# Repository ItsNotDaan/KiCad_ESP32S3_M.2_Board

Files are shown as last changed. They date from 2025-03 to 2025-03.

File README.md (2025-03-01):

## ESP32-S3, M.2 based System on Module (SOM)

This is my first KiCad project, developed over the last 2 months alongside my EPS project and work. 

[KiCanvas Webpreview of latest version](https://kicanvas.org/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)

### Main Components

- **CPU:** ESP32-S3R8
- **Flash:** W25Q16JVUXIQ (16MBIT)
- **Crystals:** 40MHz and 32.768KHz (HSE/LSE)
- **Power/Flashing/Debugging:** USB-C
- **Buck Converter:** TLV62568DBV
- **Buttons:** Two buttons for RESET and BOOT
- **Antenna:** Antenna with PI filter
- **PCB:** 4-layer PCB (Top, GND, VCC, Bottom), internal planes are hidden

All these components are included on a M.2-B-Key footprint. 

### Inspiration

The idea originated from a desire to create a more complex and smaller PCB that incorporates an expensive CPU. This CPU should be versatile enough to be used on different projects. After watching a video from Phil's Lab, I learned that M.2 was a great alternative to the mostly used header pin setup. 

### Future Plans

The ESP32-S3 is not high-end or anything special, but I plan to quickly redesign this board using the newly announced ESP32-P4. It is a really interesting and high-speed CPU based on the RISC-V architecture and I'm excited to start creating some (DSP) code with it. 

I have ordered the components and the PCB to start experimenting with it.

https://www.linkedin.com/in/daan-heetkamp/

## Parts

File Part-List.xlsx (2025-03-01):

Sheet: Parts
Designator | Value | Comment | MFR.Part # | JLCPCB Part # | Package | Manufacturer | Needs to be changed/bought? | Link
ANT1 | KH-3216-H0209 | 1206 Antennas | KH-3216-H0209 | C2925417 | 1206 | Shenzhen Kinghelm Elec | No | https://wmsc.lcsc.com/wmsc/upload/file/pdf/v2/lcsc/2404011707_Espressif-Systems-ESP32-S3FN8_C2913196.pdf
C | 3.3e-12 | 50V 3.3pF C0G 0603 | 0603CG3R3C500NT | C1660 | 0603 | FH (Guangdong Fenghua Advanced Tech)
C | 1e-11 | 50V 10pF NP0 ±5% 0402 | C1005NP0100JGTS | C258501 | 0402 | Darfon Elec |  | https://www.lcsc.com/datasheet/lcsc_datasheet_1809211012_KDS-Daishinku-DST310S-32-768KHz_C93232.pdf
C | 2e-11 | 50V 20pF NP0 ±5% 0402 | CC0402JRNPO9BN200 | C107000 | 0402 | YAGEO | No
C | 1e-07 | 25V 100nF X5R ±10% 0402 | C1005X5R1E104KT000E | C361203 | 0402 | TDK |  | https://www.lcsc.com/datasheet/lcsc_datasheet_2205122030_Winbond-Elec-W25Q16JVUXIQ_C2843335.pdf
C | 1e-06 | 10V 1uF X5R ±20% 0402 | CC0402MRX5R6BB105 | C113791 | 0402 | YAGEO | No | https://www.lcsc.com/datasheet/lcsc_datasheet_2108132230_TECH-PUBLIC-USBLC6-2SC6_C2827654.pdf
C | 4.7e-06 | 6.3V 4.7uF X5R ±20% 0402 | GRM155R60J475ME47D | C82453 | 0402 | Murata Electronics |  | http://www.world-semi.com/DownLoadFile/139
C | 1e-05 | 10V 10uF X5R ±20% 0402 | 0402X106M100CT | C2992625 | 0402 | Walsin Tech Corp
D | RED | 0402 LED Indication - Discrete ROHS | XL-1005SURC | C25503345 | 0402 | XINGLIGHT | Yes
J | USB-C | 12P Female Type-C SMD USB Connectors | MC-311D | C136423 | SMD | SOFNG | Yes
L | 2.2e-6 | 3.4A 2.2uH ±20% 3.4A SMD,4x4x2mm Power Inductors ROHS | SMNR4020-2.2UH | C135262 | SMD,4x4x2mm | SXN(Shun Xiang Nuo Elec) | No | https://www.lcsc.com/datasheet/lcsc_datasheet_2009111836_SOFNG-MC-311D_C136423.pdf
L | 2.2e-9 | 500mA 2.2nH 100mΩ 0603 | SDCL1608C2N2STDF | C29682 | 0603 | Sunlord
LED | WS2812C-2020-V1 | Intelligent control LED integrated light source | WS2812C-2020-V1 | C2976072 | SMD,2x2mm | Worldsemi | No
R | 22 | 22Ω 0402 50V 100mW ±100ppm | ERJ2RKF22R0X | C413049 | 0402 | PANASONIC
R | 5100 | 5k1Ω 0402 50V ±100ppm | RC0402JR-075K1L | C105873 | 0402 | YAGEO | No
R | 10000 | 10kΩ 0402 50V 62,5mW ±100ppm | WR04X1002FTL | C163810 | 0402 | Walsin Tech Corp
R | 100000 | 100kΩ 0402 50V ±50ppm | RT0402CRE07100KL | C705662 | 0402 | YAGEO | No
R | 450000 | 450kΩ 0402 50V 62,5mW ±100ppm | FRC0402F4503TS | C5159688 | 0402 | FOJAN
S | EVQP2P02W | 20mA 4.7mm 100MΩ 1,000,000 Times 1N 15V 3.5mm 2.5mm Rectangle button | EVQP2P02W | C512395 | SMD,3.5x4.7mm | PANASONIC | No
U | ESP32-S3R8 | Microcontroller, Wi-Fi 802.11b/g/n, Bluetooth, 32bit | ESP32-S3R8 | C2913194 | QFN-56-EP(7x7) | Espressif Systems | No
U | TLV62568DBVR | 5.5V 1A SOT-23-5 DC-DC Converters RoHS | TLV62568DBVR | C163219 | SOT-23-5 | Texas Instruments | No
U | USBLC6-2SC6 | (TVS/ESD) 6A 12V 150W 6V Unidirectional 5V SOT-23-6 ESD and Surge Protection | USBLC6-2SC6 | C2827654 | SOT-23-6 | TECH PUBLIC | No
U | W25Q16JVUXIQ | USON-8-EP(2x3) NOR FLASH | W25Q16JVUXIQ | C2843335 | USON-8-EP(2x3) | Winbond Elec | No
Y | 32.768KHz | SMD3215-2P Crystals ROHS - 32.768KHz | DST310S 32.768KHz | C93232 | SMD3215-2P | KDS Daishinku | No
Y | 40MHz | 40MHz SMD crystal oscillator 10pF ±10ppm ±20ppm SMD2520-4P Crystals ROHS | X252040MMB4SI | C2885592 | SMD2520-4P | YXC Crystal Oscillators | No

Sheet: Sheet3
Done? | Comment | MFR.Part # | JLCPCB Part # | Package | Manufacturer
Yes
Yes
Yes
Yes
Yes
Yes
Yes
Yes
Yes
Yes
Yes
Yes
Yes
Yes
Yes
No
Yes
Yes
Yes
Yes
Yes
Yes
Yes

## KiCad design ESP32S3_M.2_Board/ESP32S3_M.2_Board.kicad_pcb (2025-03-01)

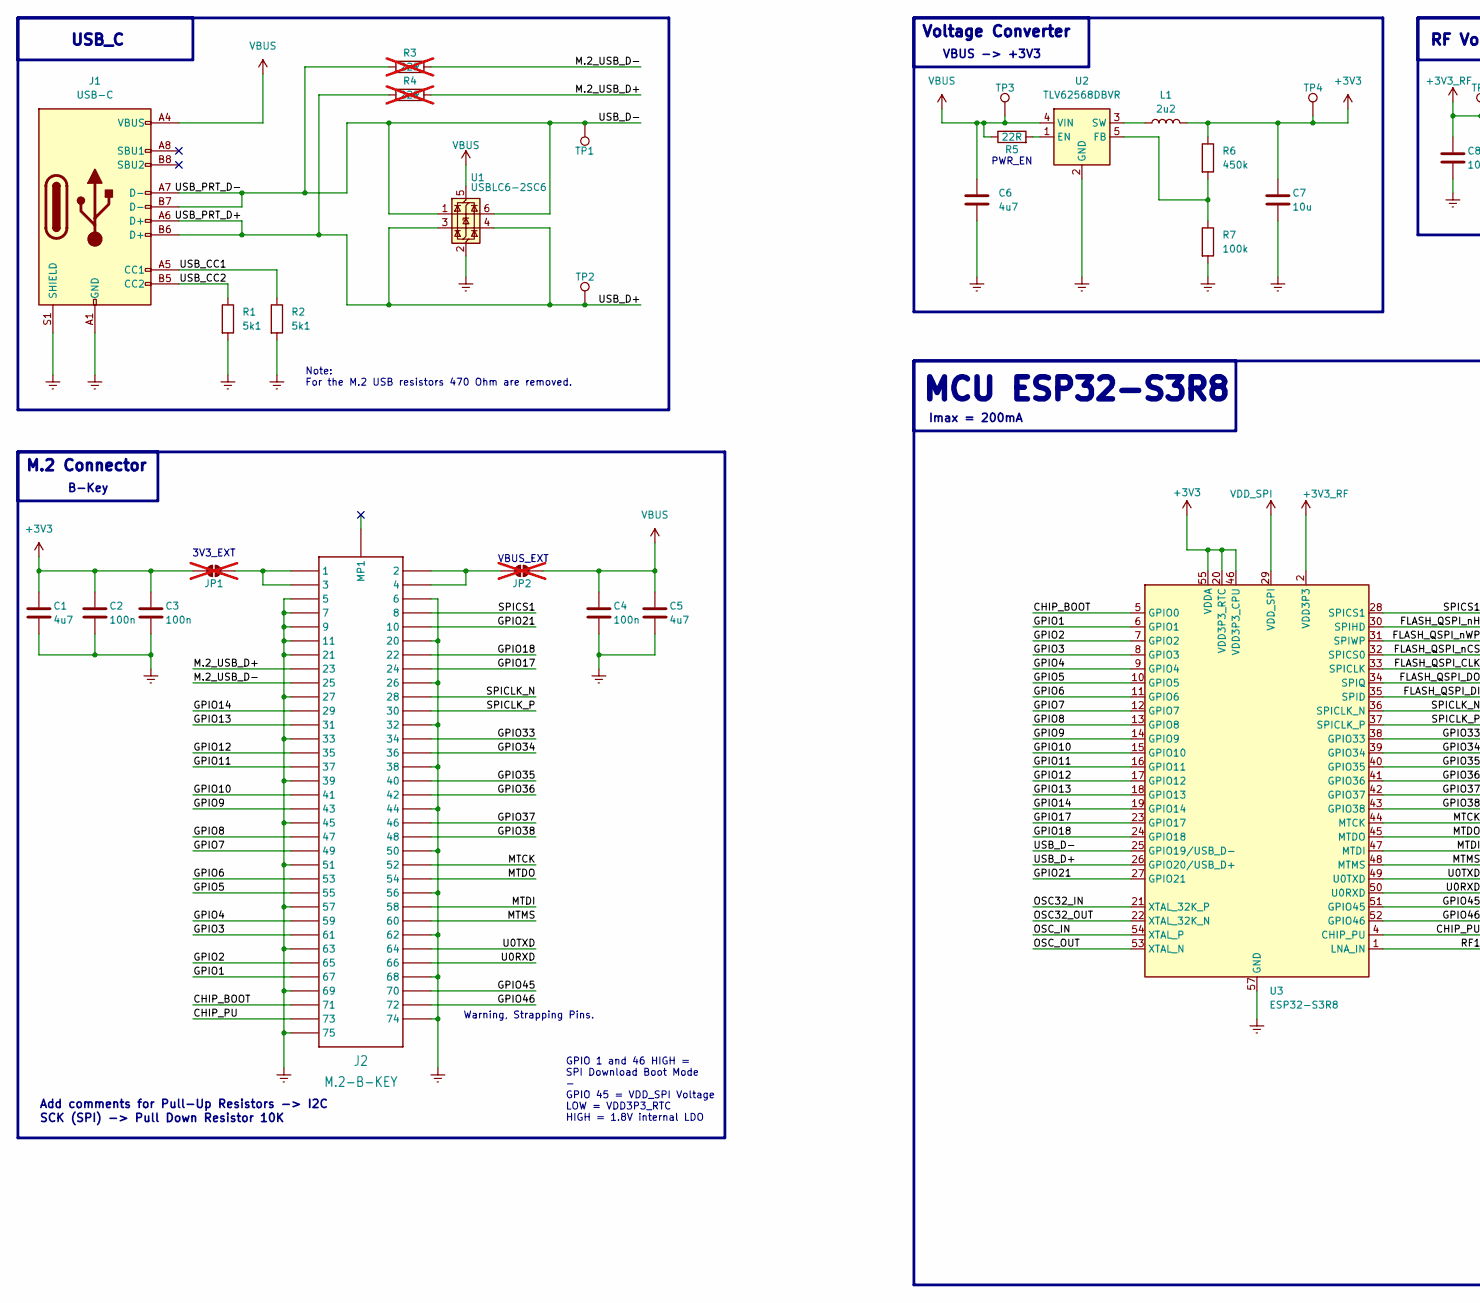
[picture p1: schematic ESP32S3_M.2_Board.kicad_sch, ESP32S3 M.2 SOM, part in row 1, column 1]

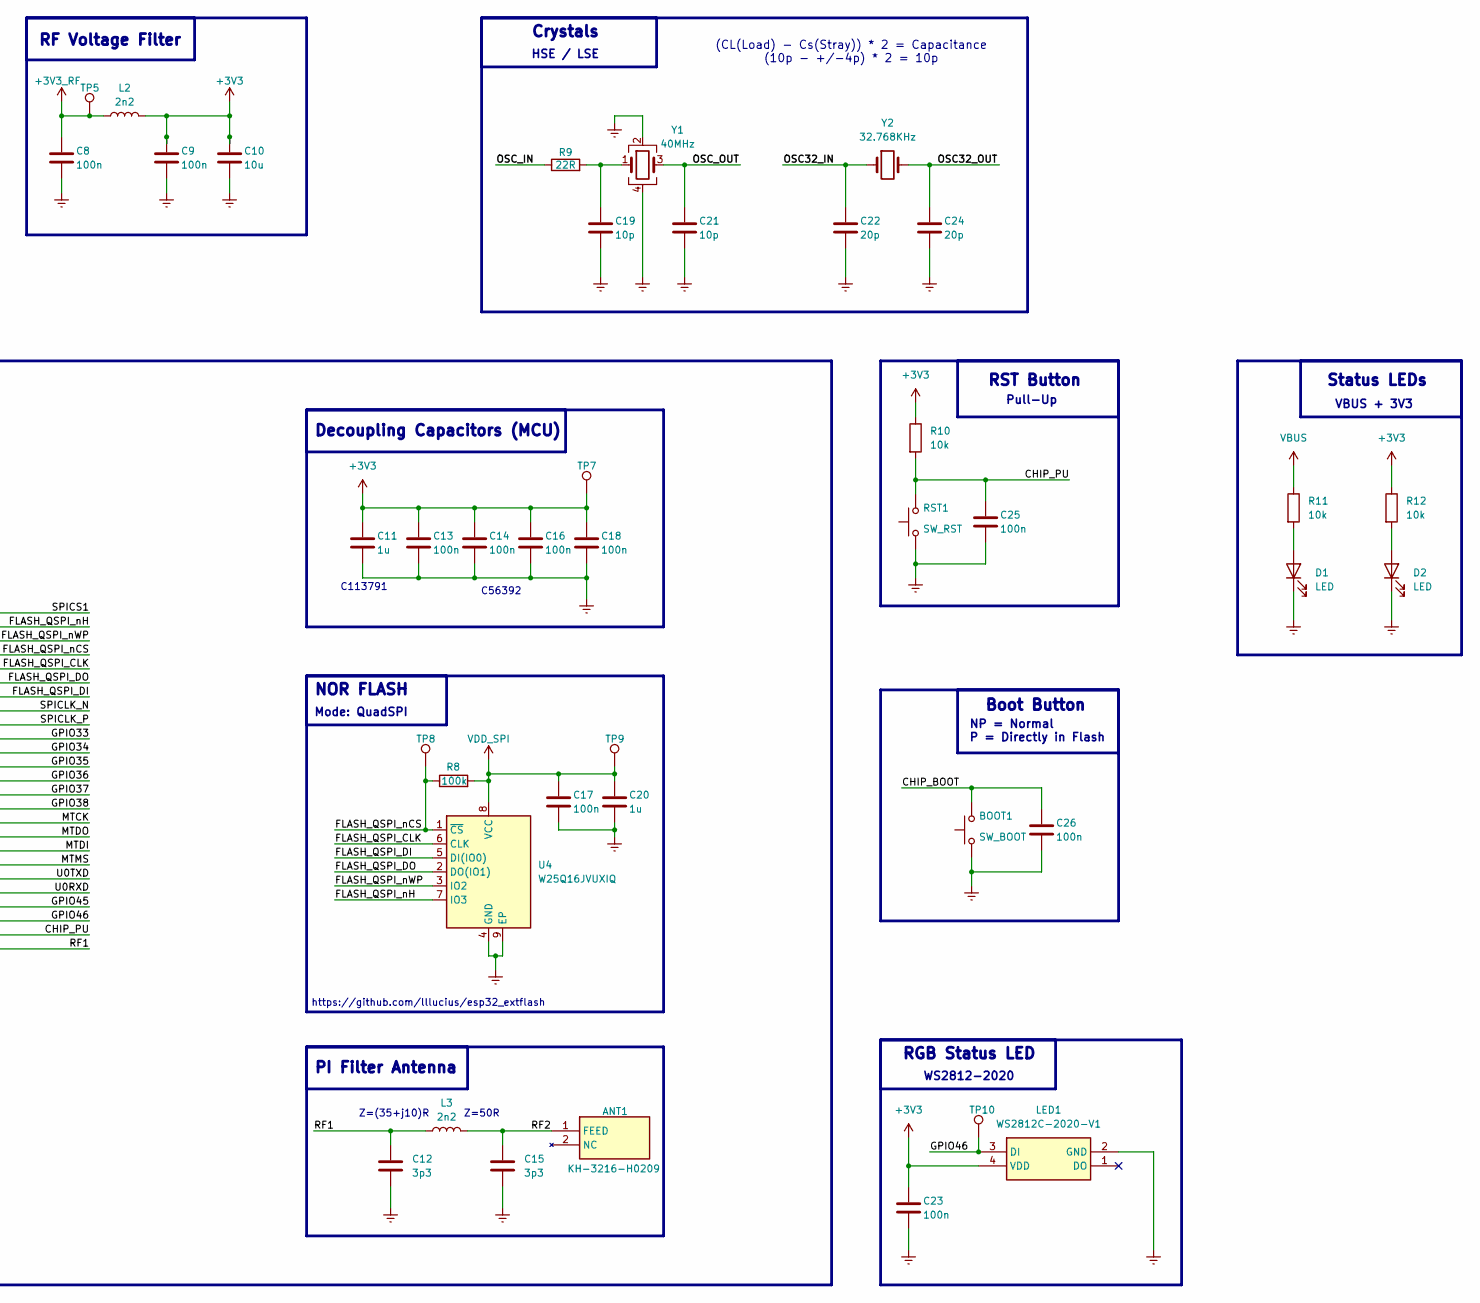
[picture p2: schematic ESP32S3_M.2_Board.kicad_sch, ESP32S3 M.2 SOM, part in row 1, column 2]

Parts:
ANT1: KH-3216-H0209; ANTC3216X140N; Manufacturer_Part_Number KH-3216-H0209; LCSC PART # C2925417
BOOT1: SW_BOOT; SW_SPST_EVQP2; Manufacturer_Part_Number EVQP2P02W; LCSC PART # C512395
C1, C5, C6: 4u7; C_0402_1005Metric_Pad0.74x0.62mm_HandSolder; Manufacturer_Part_Number GRM155R60J475ME47D; LCSC PART # C82453
C2, C3, C4, C8, C9, C13, C14, C16, C17, C18, C23, C25, C26: 100n; C_0402_1005Metric_Pad0.74x0.62mm_HandSolder; Manufacturer_Part_Number C1005X5R1E104KT000E; LCSC PART # C361203
C7, C10: 10u; C_0402_1005Metric_Pad0.74x0.62mm_HandSolder; Manufacturer_Part_Number 0402X106M100CT; LCSC PART # C2992625
C11, C20: 1u; C_0402_1005Metric_Pad0.74x0.62mm_HandSolder; Manufacturer_Part_Number CC0402MRX5R6BB105; LCSC PART # C113791
C12, C15: 3p3; C_0603_1608Metric_Pad1.08x0.95mm_HandSolder; Manufacturer_Part_Number 0603CG3R3C500NT; LCSC PART # C1660
C19, C21: 10p; C_0402_1005Metric_Pad0.74x0.62mm_HandSolder; Manufacturer_Part_Number C1005NP0100JGTS; LCSC PART # C258501
C22, C24: 20p; C_0402_1005Metric_Pad0.74x0.62mm_HandSolder; Manufacturer_Part_Number CC0402JRNPO9BN200; LCSC PART # C107000
D1, D2: LED; LED_0402_1005Metric_Pad0.77x0.64mm_HandSolder; Manufacturer_Part_Number XL-1005SURC; LCSC PART # C25503345
J1: USB-C; USB_C_Receptacle_GCT_USB4105-xx-A_16P_TopMnt_Horizontal; Manufacturer_Part_Number MC-311D; LCSC PART # C136423
J2: M.2-B-KEY
JP1: 3V3_M2; R_0201_0603Metric; not fitted
JP2: VBUS_M2; R_0201_0603Metric; not fitted
L1: 2u2; L_Wurth_WE-LQSH-4020; Manufacturer_Part_Number SMNR4020-2.2UH; LCSC PART # C135262
L2, L3: 2n2; L_0603_1608Metric_Pad1.05x0.95mm_HandSolder; Manufacturer_Part_Number SDCL1608C2N2STDF; LCSC PART # C29682
LED1: WS2812C-2020-V1; WS2812C2020; Manufacturer_Part_Number WS2812C-2020; LCSC PART # C2976072
R1, R2: 5k1; R_0402_1005Metric_Pad0.72x0.64mm_HandSolder; Manufacturer_Part_Number RC0402JR-075K1L; LCSC PART # C105873
R3, R4: 22R; R_0201_0603Metric; not fitted
R5, R9: 22R; R_0402_1005Metric_Pad0.72x0.64mm_HandSolder; Manufacturer_Part_Number ERJ2RKF22R0X; LCSC PART # C413049
R6: 450k; R_0402_1005Metric_Pad0.72x0.64mm_HandSolder; Manufacturer_Part_Number FRC0402F4503TS; LCSC PART # C5159688
R7, R8: 100k; R_0402_1005Metric_Pad0.72x0.64mm_HandSolder; Manufacturer_Part_Number RT0402CRE07100KL; LCSC PART # C705662
R10, R11, R12: 10k; R_0402_1005Metric_Pad0.72x0.64mm_HandSolder; Manufacturer_Part_Number WR04X1002FTL; LCSC PART # C163810
RST1: SW_RST; SW_SPST_EVQP2; Manufacturer_Part_Number EVQP2P02W; LCSC PART # C512395
TP1, TP2, TP3, TP4, TP5, TP7, TP8, TP9, TP10: TestPoint; TestPoint_Pad_D1.0mm
U1: USBLC6-2SC6; SOT-23-6; Manufacturer_Part_Number USBLC6-2SC6; LCSC PART # C2827654
U2: TLV62568DBVR; SOT-23-5; Manufacturer_Part_Number TLV62568DBVR; LCSC PART # C163219
U3: ESP32-S3R8; QFN-56-1EP_7x7mm_P0.4mm_EP4x4mm; Manufacturer_Part_Number ESP32-S3R8; LCSC PART # C2913194
U4: W25Q16JVUXIQ; USON-8-2X3_P0.6mm; Manufacturer_Part_Number W25Q16JVUXIQ; LCSC PART # C2843335
Y1: 40MHz; Crystal_SMD_3225-4Pin_3.2x2.5mm; Manufacturer_Part_Number X252040MMB4SI; LCSC PART # C2885592
Y2: 32.768KHz; Crystal_SMD_3215-2Pin_3.2x1.5mm; Manufacturer_Part_Number DST310S 32.768KHz; LCSC PART # C93232

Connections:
+3V3: C1.1, C2.1, C3.1, C7.1, C9.1, C10.1, C11.1, C13.1, C14.1, C16.1, C18.1, C23.1, JP1.2 (B), L1.2, L2.2, LED1.4 (VDD), R6.1, R10.1, R12.1, TP4.1, TP7.1, U3.20 (VDD3P3_RTC), U3.46 (VDD3P3_CPU), U3.55 (VDDA), U3.56 (VDDA)
+3V3_RF: C8.1, L2.1, TP5.1, U3.2 (VDD3P3), U3.3 (VDD3P3)
/CHIP_BOOT: BOOT1.2, C26.1, J2.P$71 (71), U3.5 (GPIO0)
/CHIP_PU: C25.1, J2.P$73 (73), R10.2, RST1.2, U3.4 (CHIP_PU)
/FLASH_QSPI_CLK: U3.33 (SPICLK), U4.6 (CLK)
/FLASH_QSPI_DI: U3.35 (SPID), U4.5 (DI(IO0))
/FLASH_QSPI_DO: U3.34 (SPIQ), U4.2 (DO(IO1))
/FLASH_QSPI_nCS: R8.1, TP8.1, U3.32 (SPICS0), U4.1 (~CS)
/FLASH_QSPI_nH: U3.30 (SPIHD), U4.7 (IO3)
/FLASH_QSPI_nWP: U3.31 (SPIWP), U4.3 (IO2)
/GPIO1: J2.P$67 (67), U3.6 (GPIO1)
/GPIO2: J2.P$65 (65), U3.7 (GPIO2)
/GPIO3: J2.P$61 (61), U3.8 (GPIO3)
/GPIO4: J2.P$59 (59), U3.9 (GPIO4)
/GPIO5: J2.P$55 (55), U3.10 (GPIO5)
/GPIO6: J2.P$53 (53), U3.11 (GPIO6)
/GPIO7: J2.P$49 (49), U3.12 (GPIO7)
/GPIO8: J2.P$47 (47), U3.13 (GPIO8)
/GPIO9: J2.P$43 (43), U3.14 (GPIO9)
/GPIO10: J2.P$41 (41), U3.15 (GPIO10)
/GPIO11: J2.P$37 (37), U3.16 (GPIO11)
/GPIO12: J2.P$35 (35), U3.17 (GPIO12)
/GPIO13: J2.P$31 (31), U3.18 (GPIO13)
/GPIO14: J2.P$29 (29), U3.19 (GPIO14)
/GPIO17: J2.P$24 (24), U3.23 (GPIO17)
/GPIO18: J2.P$22 (22), U3.24 (GPIO18)
/GPIO21: J2.P$10 (10), U3.27 (GPIO21)
/GPIO33: J2.P$34 (34), U3.38 (GPIO33)
/GPIO34: J2.P$36 (36), U3.39 (GPIO34)
/GPIO35: J2.P$40 (40), U3.40 (GPIO35)
/GPIO36: J2.P$42 (42), U3.41 (GPIO36)
/GPIO37: J2.P$46 (46), U3.42 (GPIO37)
/GPIO38: J2.P$48 (48), U3.43 (GPIO38)
/GPIO45: J2.P$70 (70), U3.51 (GPIO45)
/GPIO46: J2.P$72 (72), LED1.3 (DI), TP10.1, U3.52 (GPIO46)
/M.2_USB_D+: J2.P$23 (23), R4.2
/M.2_USB_D-: J2.P$25 (25), R3.2
/MTCK: J2.P$52 (52), U3.44 (MTCK)
/MTDI: J2.P$58 (58), U3.47 (MTDI)
/MTDO: J2.P$54 (54), U3.45 (MTDO)
/MTMS: J2.P$60 (60), U3.48 (MTMS)
/OSC32_IN: C22.1, U3.21 (XTAL_32K_P), Y2.1
/OSC32_OUT: C24.1, U3.22 (XTAL_32K_N), Y2.2
/OSC_IN: R9.1, U3.54 (XTAL_P)
/OSC_OUT: C21.1, U3.53 (XTAL_N), Y1.3
/RF1: C12.1, L3.1, U3.1 (LNA_IN)
/RF2: ANT1.1 (FEED), C15.1, L3.2
/SPICLK_N: J2.P$28 (28), U3.36 (SPICLK_N)
/SPICLK_P: J2.P$30 (30), U3.37 (SPICLK_P)
/SPICS1: J2.P$8 (8), U3.28 (SPICS1)
/U0RXD: J2.P$66 (66), U3.50 (U0RXD)
/U0TXD: J2.P$64 (64), U3.49 (U0TXD)
/USB_CC1: J1.A5 (CC1), R2.1
/USB_CC2: J1.B5 (CC2), R1.1
/USB_D+: J1.A6 (D+), J1.B6 (D+), R4.1, TP2.1, U1.3 (I/O2), U1.4 (I/O2), U3.26 (GPIO20/USB_D+)
/USB_D-: J1.A7 (D-), J1.B7 (D-), R3.1, TP1.1, U1.1 (I/O1), U1.6 (I/O1), U3.25 (GPIO19/USB_D-)
Earth: BOOT1.1, C1.2, C2.2, C3.2, C4.2, C5.2, C6.2, C7.2, C8.2, C9.2, C10.2, C11.2, C12.2, C13.2, C14.2, C15.2, C16.2, C17.2, C18.2, C19.2, C20.2, C21.2, C22.2, C23.2, C24.2, C25.2, C26.2, D1.1 (K), D2.1 (K), J1.A1 (GND), J1.A12 (GND), J1.B1 (GND), J1.B12 (GND), J1.S1 (SHIELD), J2.P$5 (5), J2.P$6 (6), J2.P$7 (7), J2.P$9 (9), J2.P$11 (11), J2.P$20 (20), J2.P$21 (21), J2.P$26 (26), J2.P$27 (27), J2.P$32 (32), J2.P$33 (33), J2.P$38 (38), J2.P$39 (39), J2.P$44 (44), J2.P$45 (45), J2.P$50 (50), J2.P$51 (51), J2.P$56 (56), J2.P$57 (57), J2.P$62 (62), J2.P$63 (63), J2.P$68 (68), J2.P$69 (69), J2.P$74 (74), J2.P$75 (75), LED1.2 (GND), R1.2, R2.2, R7.2, RST1.1, U1.2 (GND), U2.2 (GND), U3.57 (GND), U4.4 (GND), U4.9 (EP), Y1.2, Y1.4
unnamed: C19.1, R9.2, Y1.1
unnamed: D1.2 (A), R11.2
unnamed: D2.2 (A), R12.2
unnamed: J2.P$1 (1), J2.P$3 (3), JP1.1 (A)
unnamed: J2.P$2 (2), J2.P$4 (4), JP2.2 (B)
unnamed: R5.2, U2.1 (EN)
unnamed: R6.2, R7.1, U2.5 (FB)
unnamed: L1.1, U2.3 (SW)
VBUS: C4.1, C5.1, C6.1, J1.A4 (VBUS), J1.A9 (VBUS), J1.B4 (VBUS), J1.B9 (VBUS), JP2.1 (A), R5.1, R11.1, TP3.1, U1.5 (VBUS), U2.4 (VIN)
VDD_SPI: C17.1, C20.1, R8.2, TP9.1, U3.29 (VDD_SPI), U4.8 (VCC)

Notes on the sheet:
RGB Status LED
VBUS_EXT
3V3_EXT
VBUS + 3V3
Crystals
B-Key
NP = Normal P = Directly in Flash
HSE / LSE
Note: For the M.2 USB resistors 470 Ohm are removed.
Add comments for Pull-Up Resistors -> I2C
Voltage Converter
MCU ESP32-S3R8
RF Voltage Filter
Mode: QuadSPI
NOR FLASH
USB_C
C113791
SCK (SPI) -> Pull Down Resistor 10K
M.2 Connector
RST Button
WS2812-2020
PWR_EN
Decoupling Capacitors (MCU)
Boot Button
C56392
Status LEDs
Warning, Strapping Pins.
VBUS -> +3V3
GPIO 1 and 46 HIGH = SPI Download Boot Mode - GPIO 45 = VDD_SPI Voltage LOW = VDD3P3_RTC HIGH = 1.8V internal LDO
Z=(35+j10)R
PI Filter Antenna
(CL(Load) - Cs(Stray)) * 2 = Capacitance (10p - +/-4p) * 2 = 10p
Imax = 200mA
Z=50R
https://github.com/lllucius/esp32_extflash
Pull-Up

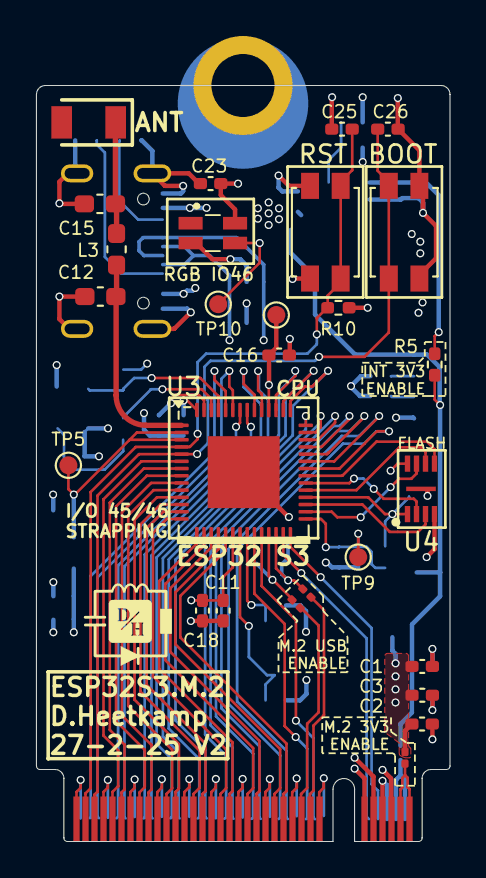
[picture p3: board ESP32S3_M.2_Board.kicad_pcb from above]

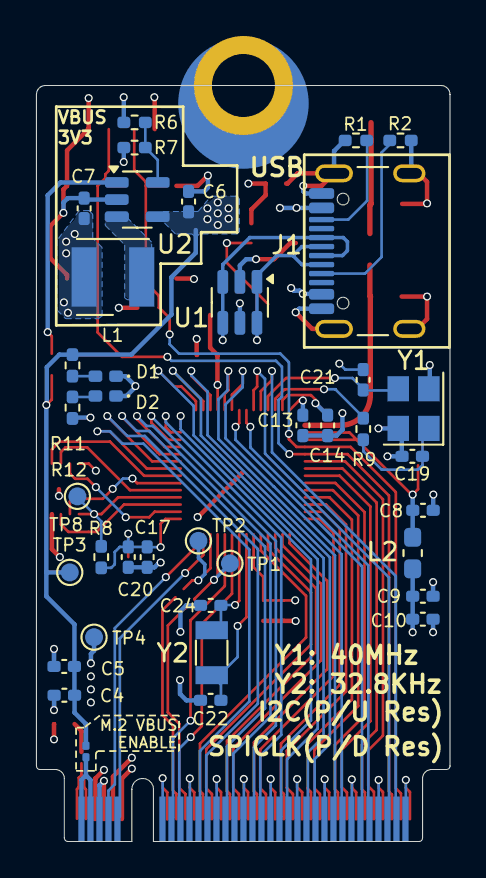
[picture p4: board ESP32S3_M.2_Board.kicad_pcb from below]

Board: 4 copper layers, 23.0 x 42.0 mm, 66 parts (38 on the bottom side), 67 nets.

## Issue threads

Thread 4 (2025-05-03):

3D models

jharvey, 2025-05-03:
Antenna model and WS2812 LED model does not appear to be there. See attached step files. They are 1:1 only need to be rotated 90 on the X axis.

The 3D for the WS2812 LED was found here https://cad.onshape.com/documents/4ae596870789773a1f3883ab/w/270b351a80455c606ef10f16/e/bb2cb23d0cde59a574ea0ed1

The 3D for the antenna was found EasyEDA.

[3D-for-M2-Project.zip](https://github.com/user-attachments/files/20022805/3D-for-M2-Project.zip)

ItsNotDaan, 2025-05-16:
Hi Harvey,

Are you sure they are not there? When I opened the file it did seem to be attached.

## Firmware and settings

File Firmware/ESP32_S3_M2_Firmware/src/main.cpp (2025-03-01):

#include <Arduino.h>
#include <LED.h>

/*To do:
  - Add the SPI flash memory. DONE
  - Add the RGB LED. DONE
  - Check the USB connection.
  - Add some DSP functions in Espressif IoT Development Framework.
  - Add a WiFi connection. 
  - Add a Bluetooth connection.

*/

void setup() {
  // put your setup code here, to run once:
  
  //Init LED
  FastLED.addLeds<LED_TYPE, DATA_PIN, COLOR_ORDER>(leds, NUM_LEDS);
}

void loop() {
  // put your main code here, to run repeatedly:
  RGB_LED(true, 255, 0, 0);
  delay(1000);
  RGB_LED(false, 0, 0, 0);
  delay(1000);
}

// ESP32S3 PINS	ESP32S3 PIN_FUNCT	USED_PINS	M.2_USED_PINS	EXTRA_INFORMATION
// 1	LNA_IN	-	-	-
// 2	VDD3P3	-	-	-
// 3	VDD3P3	-	-	-
// 4	CHIP_PU	CHIP_PU	73	-
// 5	GPIO0	CHIP_BOOT	71	-
// 6	GPIO1	GPIO1	67	-
// 7	GPIO2	GPIO2	65	-
// 8	GPIO3	GPIO3	61	-
// 9	GPIO4	GPIO4	59	-
// 10	GPIO5	GPIO5	55	-
// 11	GPIO6	GPIO6	53	-
// 12	GPIO7	GPIO7	49	-
// 13	GPIO8	GPIO8	47	-
// 14	GPIO9	GPIO9	43	-
// 15	GPIO10	GPIO10	41	-
// 16	GPIO11	GPIO11	37	-
// 17	GPIO12	GPIO12	35	-
// 18	GPIO13	GPIO13	31	-
// 19	GPIO14	GPIO14	29	-
// 20	VDD3P3_RTC	-	-	-
// 21	XTAL_32K_P	-	-	-
// 22	XTAL_32K_N	-	-	-
// 23	GPIO17	GPIO17	24	-
// 24	GPIO18	GPIO18	22	-
// 25	GPIO19/USB_D-	USB_D-	25	Solder_Pad
// 26	GPIO20/USB_D+	USB_D+	23	Solder_Pad
// 27	GPIO21	GPIO21	10	-
// 28	SPICS1	SPICS1	8	-
// 29	VDD_SPI	-	-	-
// 30	SPIHD	-	-	-
// 31	SPIWP	-	-	-
// 32	SPICS0	-	-	-
// 33	SPICLK	-	-	-
// 34	SPIQ	-	-	-
// 35	SPID	-	-	-
// 36	SPICLK_N	SPICLK_N	28	-
// 37	SPICLK_P	SPICLK_P	30	-
// 38	GPIO33	GPIO33	34	-
// 39	GPIO34	GPIO34	36	-
// 40	GPIO35	GPIO35	40	-
// 41	GPIO36	GPIO36	42	-
// 42	GPIO37	GPIO37	46	-
// 43	GPIO38	GPIO38	48	-
// 44	MTCK	MTCK	53	-
// 45	MTDO	MTDO	54	-
// 46	VDD3P3_CPU	-	-	-
// 47	MTDI	MTDI	58	-
// 48	MTMS	MTMS	60	-
// 49	U0TXD	U0TXD	64	-
// 50	U0RXD	U0RXD	66	-
// 51	GPIO45	GPIO45	70	Pull_Up_Res/Strapping Pins
// 52	GPIO46	GPIO46	72	RGB_LED
// 53	XTAL_N	-	-	-
// 54	XTAL_P	-	-	-
// 55	VDDA	-	-	-
// 56	VDDA	-	-	-
// 57	GND	-	-	-

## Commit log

2024-04-24 feat: full push
    [BOM.xlsx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]
2024-04-24 Removed unneccesary things
    [designators.csv]
2024-05-08 Firmware Adding
    [BOM.xlsx, ESP32S3_M.2_Board.kicad_pcb, PINOUT.xlsx]
2025-03-01 feat: push for v.2
    [BOM.xlsx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]
